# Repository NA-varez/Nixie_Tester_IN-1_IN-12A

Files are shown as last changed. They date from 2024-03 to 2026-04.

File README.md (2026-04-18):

# Nixie Tube Tester - IN-1 and IN-12A

https://github.com/user-attachments/assets/7158ab72-1c5b-4f93-8375-850d6015da81

## The Nixie Tube

First, here are the parts of a nixie tube.
  * The Grid    - The anode, is the wire-mesh tied to HV (high-voltage ~160 to 180V) 
  * The Digits  - Each digit is a ceramically separated cathode
  * The Gas     - Inert low-pressure gas mixture, primarily Neon
  * The Tube    - Air-tight glass tube to keep gas inside
  
  The orange glow is not a resistive glow produced by heat.  Instead, the glow is produced
  by a combination of mid-air collisions between gas ions and electrons moving in opposite directions
  and sputtering caused by positive ions hitting the cathode digit directly.
  
  The Nixie tube is a current-driven device and requires an anode resistor between the grid and HV.
  Every digit can be individually controlled via a transistor tying the cathode to ground when powered.

<div align="center">
  <a href="https://github.com/NA-varez/Nixie_Tester_IN-1_IN-12A/">
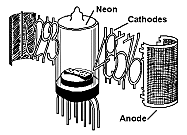
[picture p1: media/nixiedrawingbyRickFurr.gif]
    
  </a>
</div>

## The Nixie Tester

1. Astable 555 timer clocks a Counter chip that cycles through its 10 outputs.
2. Every output from the Counter chip is tied to the base of a transistor darlington pair.
3. Orange glow occurs when the transistor is turned on and completes the circuit from HV to ground.`

## More Detail

- An external HV supply is required. Look for one that has a maximum voltage output of at least 180V.
- For the IN-1 Nixie tube, look for "100 PCS Delphi MOLEX automotive 0002091102 Socket Contact Tin 14-20 AWG FEMALE" on Ebay
- R5 is a variable resistor that can be adjusted to change the speed of clock generated from the astable configured 555-timer.
- The output of the 555-timer acts as the clock for a counter IC that cycles through its 10 outputs.
- Those 10 outputs are input to 2 Darlington Arrays (chips) that have a 100V collector-emitter breakdown voltage to handle the required cathode biasing for the nixie tube.
- A Zener is biased with a resistor to produce the 91V cathode bias.

## Photos

<div align="center">
  <a href="https://github.com/NA-varez/Nixie_Tester_IN-1_IN-12A/">
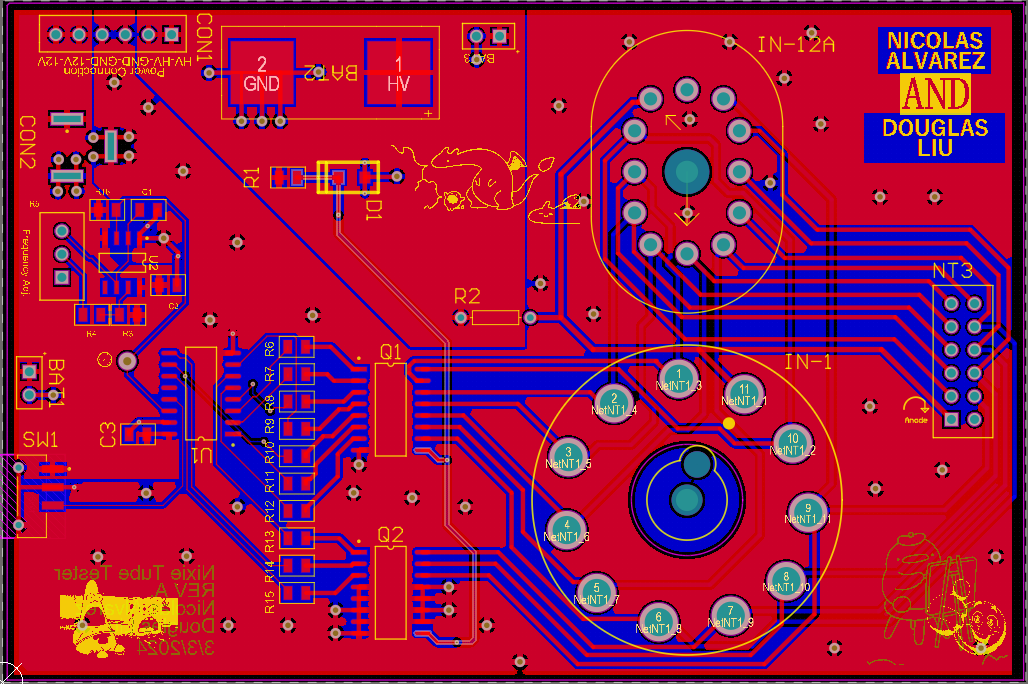
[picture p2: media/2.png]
    
  </a>
</div>

<div align="center">
  <a href="https://github.com/NA-varez/Nixie_Tester_IN-1_IN-12A/">
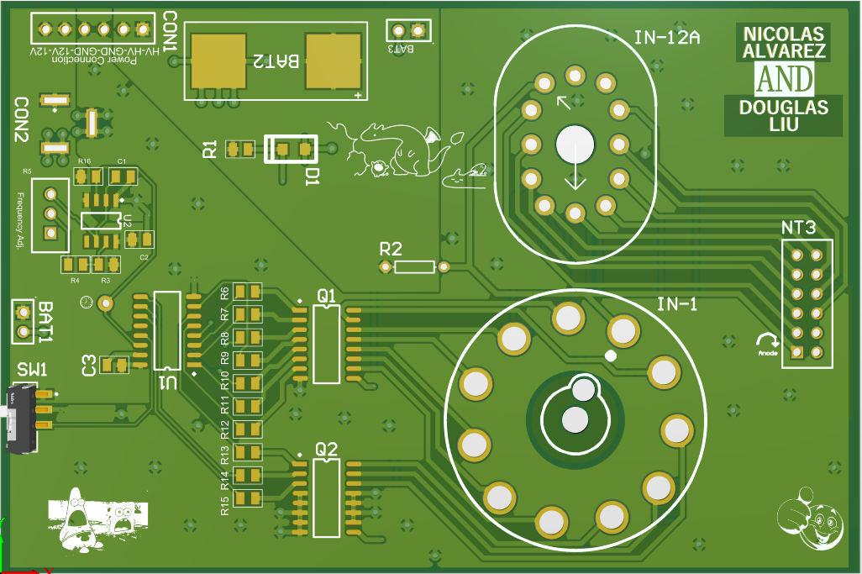
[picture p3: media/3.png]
    
  </a>
</div>

### Tools

* Altium and Altium Workspace
* Gerber Viewer 7.0

### References

* [Threeneuron](https://threeneurons.wordpress.com/nixie-power-supply/)
* [Nixie Tube Figure](https://www.vcalc.net/display2.htm)
* [Markdown Guide](https://www.markdownguide.org/basic-syntax/#reference-style-links)
* [Footprint Reference Guide](https://www.slideshare.net/abishus/smt-notes)
* [IN-1 Socket Contact](https://www.ebay.com/itm/302480301206?_skw=100+PCS+Delphi+MOLEX+automotive+0002091102)
* [Nixie Tube](https://www.explainthatstuff.com/how-nixie-tubes-work.html)

## Lessons Learned

* Empirically proven, any larger than 180V does not make the nixie tube any visibly brighter. Better to run at 180V or lower to preserve tube lifetime.
* Remove the outline from the keepout layer .GKO to prevent any confusion or delay when getting the board fabbed.
* Surface-mount soldering is easier said than done. Easier if you have higher-quality tools, more specifically an inductive rather than resistive heating iron.

## To-Do

- [X] Figure out how to bias the cathode and what components to use for cycling through cathodes
- [x] Create footprints for edge connections
- [X] Order board (Used JLC PCB)
- [X] Remove gerber .GKO Keepout layer outline. Not needed. The .GM layer already takes care of the board outline
- [X] Assemble and test the board
- [X] Make any fixes to the board (especially Nixie tube footprints) for it to be a reliable design for others

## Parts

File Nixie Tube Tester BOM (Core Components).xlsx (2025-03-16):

Name | Part Number | Qty | Description | Price | Distributor | Datasheet Link
Darlington Pair Array | SN75468DR | 2 | Bipolar (BJT) Transistor Array 7 NPN Darlington 100V 500mA Surface Mount 16-SOIC | 0.86 | Digkey | https://www.ti.com/lit/ds/symlink/sn75468.pdf?ts=1698334721719
Zener Diode | BZD27C91P-E3-08 | 1 | Zener Diode 91 V 800 mW Surface Mount DO-219AB (SMF) | 0.38 | Digkey | https://www.vishay.com/docs/85153/bzd27series.pdf
Decade Counter | CD4017BM96 | 1 | Counter IC Counter, Decade 1 Element 10 Bit Positive, Negative 16-SOIC | 0.53 | Digkey | https://www.ti.com/lit/ds/symlink/cd4017b.pdf?ts=1698495524782
555 Timer | NE555DR | 1 | 555 Type, Timer/Oscillator (Single) IC 100kHz 8-SOIC | 0.43 | Digkey | https://www.ti.com/lit/ds/symlink/se555.pdf?HQS=dis-dk-null-digikeymode-dsf-pf-null-wwe&ts=1698504051555

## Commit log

2024-03-09 Recorded in github repo
    [Nixie Tester.SchDoc, Nixie Tube Tester.PrjPcb, PcbParts.PcbLib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]
2025-03-16 Update README.md
    added socket contact ebay link
2025-03-16 Added simple BOM
    main electronic components besides resistors and nixie tubes
    [Nixie Tube Tester BOM (Core Components).xlsx]
2026-04-18 refresh hardware files
    [Nixie Tester.SchDoc, Nixie Tube Tester.PrjPcb, PcbParts.PcbLib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]
